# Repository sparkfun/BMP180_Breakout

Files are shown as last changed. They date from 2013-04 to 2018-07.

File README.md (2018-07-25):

**NOTE:** *This product has been retired from our catalog. If you are looking for more up-to-date info, please check out some of these resources to see how other users are still hacking and improving on this product.*
* *[SparkFun Forum](https://forum.sparkfun.com/)*
* *[Comments Here on GitHub](https://github.com/sparkfun/BMP180_Breakout_Arduino_Library/issues)*
* *[IRC Channel](https://www.sparkfun.com/news/263)*

BMP180_Breakout
===============

Breakout board and example code for the Bosch BMP180 barometric pressure sensor.

BMP180 Breakout

Product page: [www.sparkfun.com/products/11824](https://www.sparkfun.com/products/11824)

Datasheet: [github.com/sparkfun/BMP180_Breakout/blob/master/BMP180 Datasheet V2.5.pdf](https://github.com/sparkfun/BMP180_Breakout/blob/master/BMP180%20Datasheet%20V2.5.pdf?raw=true)

Github repository: [github.com/sparkfun/BMP180_Breakout](https://github.com/sparkfun/BMP180_Breakout)

Arduino library installation:
-------------------

This archive contains an Arduino library and example sketch showing how to use this sensor. The library must be installed onto your computer in order for the example code to work correctly.

If you haven't, install the free Arduino IDE (Integrated Development Environment), available at [www.arduino.cc](http://www.arduino.cc). This code was written using Arduino version 1.0.5. and updated to be used with the Arduino library manager of version 1.6.3.

To install without the manager, download the Arduino folder then use the Arduino IDE to add it.  From the IDE, go Sketch->Include Library->"Add .ZIP Library", then choose the Arduino folder that was downloaded.  The IDE will pick proper names from the library.properties file and put the libraries in your user sketch folder.

Teensy library installation:
-------------------

[A. Faruk](https://github.com/unalfaruk) was kind enough to create a version of this library for the [Teensy](https://www.pjrc.com/teensy/) microcontroller family. You can find information on installation and use of this library at: https://github.com/sparkfun/BMP180_Breakout/tree/master/Libraries/Teensy

Running the example sketch:
-------------------

<ol start=1>
<li>Connect the BMP180 breakout board to your Arduino. You can solder wires, use jumper wires and headers, etc.
<p>
"-" (GND) to GND
<br>
"+" (VDD) to 3.3V
<p>
(WARNING: do not connect "+" to 5V or the sensor will be damaged!)
<p>
You will also need to connect the I2C pins (SCL and SDA) to your Arduino.
These pins are different on different Arduino models:
<p>
<table>
<tr>
<td>Any Arduino</td>
<td>SDA&nbsp;</td>
<td>SCL</td>
</tr>
<tr>
<td>Uno, Redboard, Pro/Mini&nbsp;</td>
<td>A4</td>
<td>A5</td>
</tr>
<tr>
<td>Mega2560, Due</td>
<td>20</td>
<td>21</td>
</tr>
<tr>
<td>Leonardo, Pro/Micro</td>
<td>2</td>
<td>3</td>
</tr>
</table>
<p>
Leave the IO (VDDIO) pin unconnected. This pin is for connecting
the BMP180 to systems with lower logic levels such as 1.8V.
</li>
<li>
Connect your Arduino to your computer.
<p>
</li>
<li>
Start the Arduino IDE. Select the proper COM port and board type.
<p>
</li>
<li>
In the Arduino IDE, go to the File menu, and down to Examples/SFE_BMP180/SFE_BMP180_example. If you do not see this item, you likely did not install the library properly. See above.
<p>
</li>
<li>
Upload the sketch to your Arduino.
<p>
</li>
<li>
Open the Serial Monitor window (magnifying glass icon un upper right of IDE).
<p>
</li>
<li>
Set the Serial Monitor to 9600 baud (menu in bottom right).
<p>
</li>
</ol>
You should now be seeing pressure measurements in the Serial Monitor window. If you see errors, you may not have connected the BMP180 Breakout Board to your Arduino properly. See step 1 above.

If you have questions, don't hesistate to contact us at techsupport@sparkfun.com.

Have fun!
Your friends at SparkFun.

License Informatiom
-------------------

Software and hardware license information can be found at: https://github.com/sparkfun/BMP180_Breakout/blob/master/LICENSE.md

Authors
-------

 * Mike Grusin, SparkFun Electronics

Acknowledgements
----------------

 * The SFE_BMP180 library uses [floating-point equations](http://wmrx00.sourceforge.net/Arduino/BMP085-Calcs.pdf) for the BMP085 developed by the [Weather Station Data Logger project](http://wmrx00.sourceforge.net/).

  * Thank you to [A. Faruk](https://github.com/unalfaruk) for modifications to support the PJRC Teensy microcontroller family.

  * Thank you to [Asafe Silva](https://github.com/AsafeSilva) for providing support for alternate I2C implementations.

Changelog
---------
+ Release [V_1.1.0](https://github.com/sparkfun/BMP180_Breakout/tree/V_1.1.0)
	* Restructred for arduino IDE
	* Pulled in library

+ hardware V10 (release)

	* Minor updates
	* Library fork from SFE_BMP085

+ hardware V02 (proto)

	* Rearranged header: put VDD/GND/SDA/SCL in "standard" order
	* I2C pullups to VDDIO

+ hardware V01 (review)

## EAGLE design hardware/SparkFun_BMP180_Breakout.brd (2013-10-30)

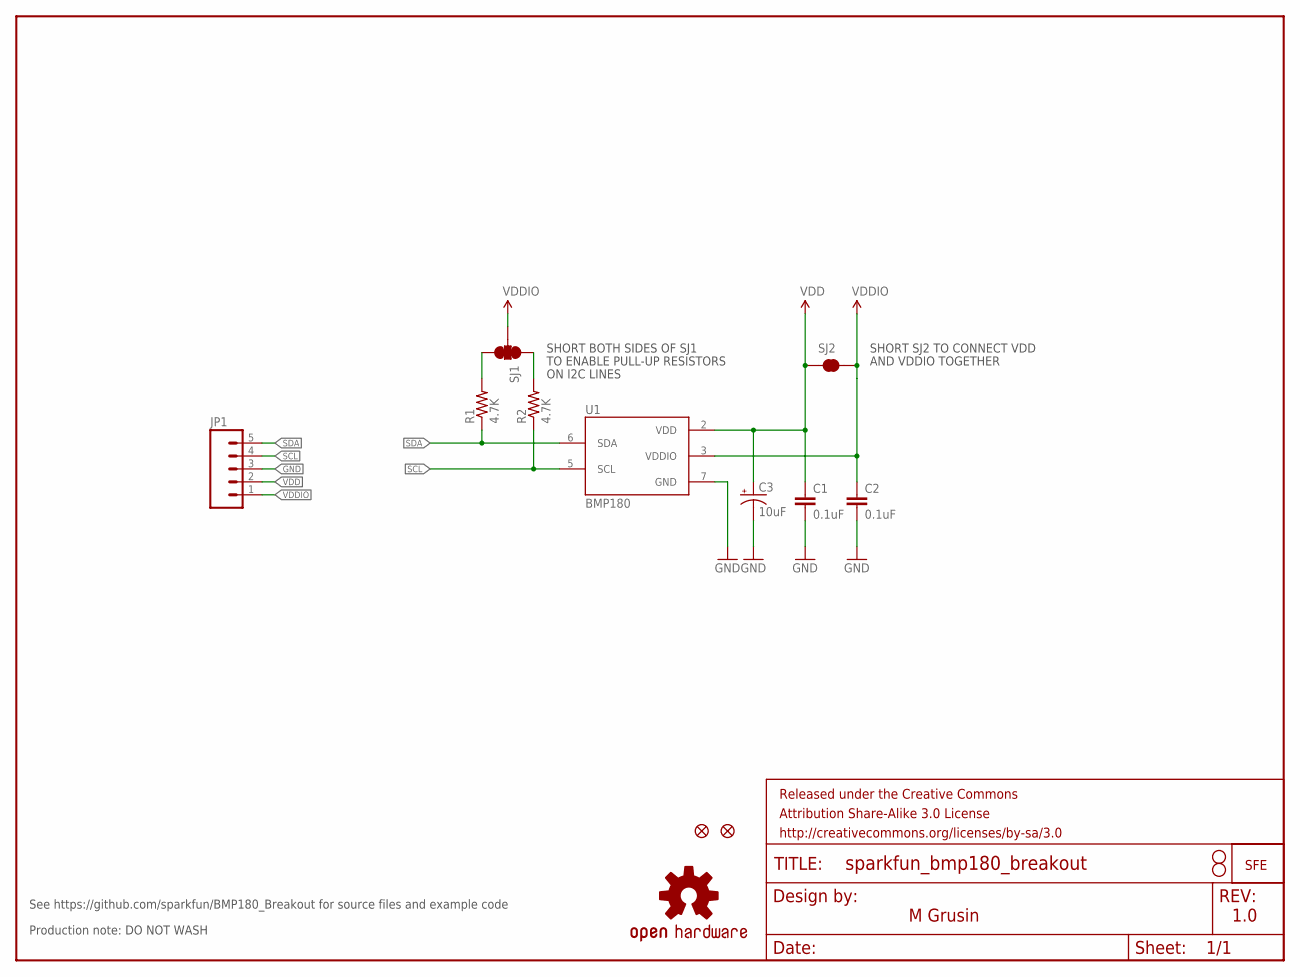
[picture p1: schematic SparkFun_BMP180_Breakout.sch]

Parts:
C1, C2: 0.1uF; 0603-CAP
C3: 10uF; EIA3216
FID1, FID2: FIDUCIALUFIDUCIAL; MICRO-FIDUCIAL
FRAME1: FRAME-LETTER; CREATIVE_COMMONS
JP1: M05_ROUNDONLY_NOSILK; 1X05_ROUNDONLY_NOSILK
LOGO1: LOGO-SFENW2; SFE-NEW-WEB
LOGO2: OSHW-LOGOS; OSHW-LOGO-S
R1, R2: 4.7K; 0603-RES
SJ1: SOLDERJUMPER_2WAYPASTE1&2&3; SJ_3_PASTE1&2&3
SJ2: SOLDERJUMPERNC; SJ_2S
STANDOFF1, STANDOFF2: STAND-OFF
U1: BMP180

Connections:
GND: C1.2, C2.2, C3.C (-), JP1.3, U1.7 (GND)
unnamed: R1.2, SJ1.3
unnamed: R2.2, SJ1.1
SCL: JP1.4, R2.1, U1.5 (SCL)
SDA: JP1.5, R1.1, U1.6 (SDA)
VDD: C1.1, C3.A (+), JP1.2, SJ2.1, U1.2 (VDD)
VDDIO: C2.1, JP1.1, SJ1.2, SJ2.2, U1.3 (VDDIO)

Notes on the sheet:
M Grusin
SHORT BOTH SIDES OF SJ1
TO ENABLE PULL-UP RESISTORS
ON I2C LINES
SHORT SJ2 TO CONNECT VDD
AND VDDIO TOGETHER
1.0
Production note: DO NOT WASH
See https://github.com/sparkfun/BMP180_Breakout for source files and example code

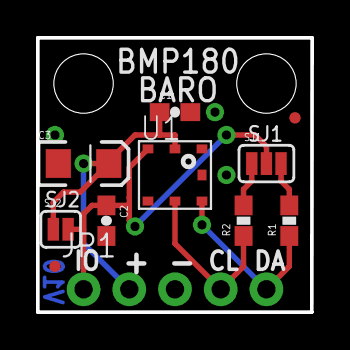
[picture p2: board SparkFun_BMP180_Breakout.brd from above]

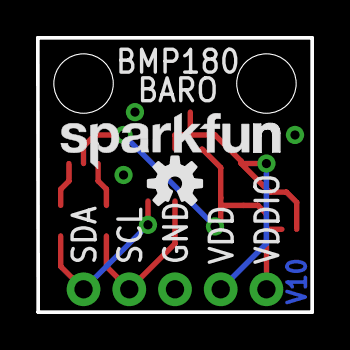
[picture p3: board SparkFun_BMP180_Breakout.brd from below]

Board: 2 copper layers, 15.2 x 15.2 mm, 16 parts (2 on the bottom side), 7 nets.

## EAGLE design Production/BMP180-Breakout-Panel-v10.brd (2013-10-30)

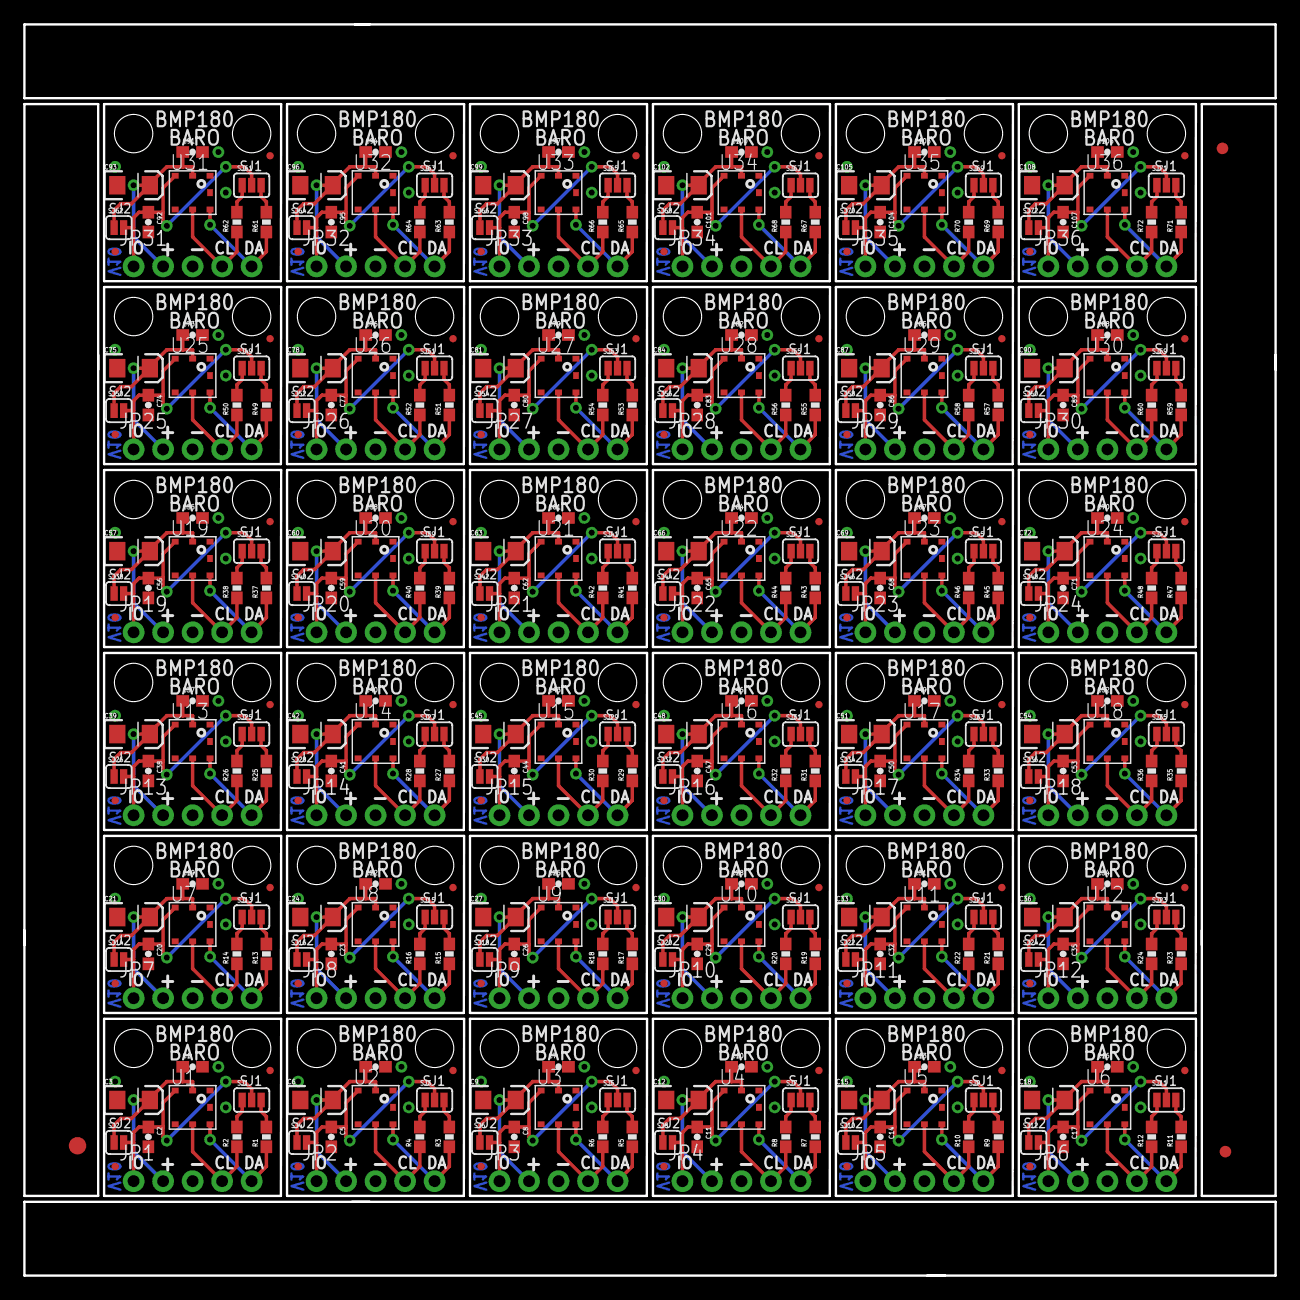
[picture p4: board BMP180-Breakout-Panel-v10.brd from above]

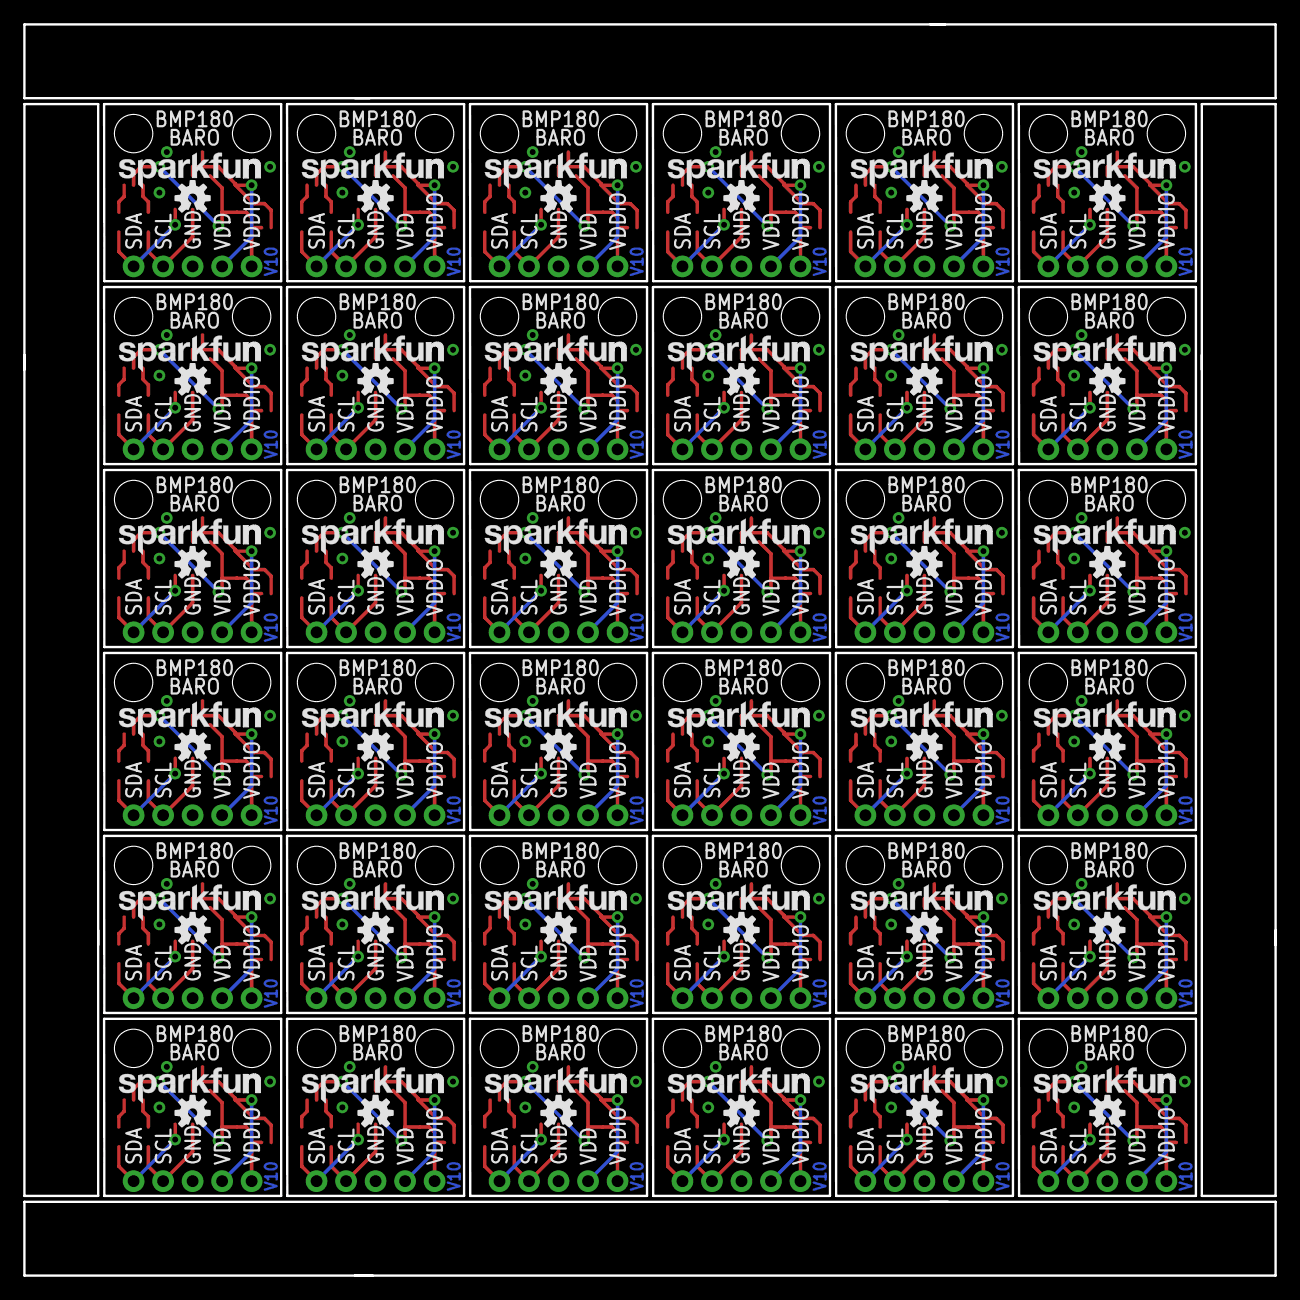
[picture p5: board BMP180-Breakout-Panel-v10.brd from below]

Board: 2 copper layers, 107.7 x 107.7 mm, 543 parts (72 on the bottom side), 252 nets.

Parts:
C1, C2, C4, C5, C7, C8, C10, C11, C13, C14, C16, C17, C19, C20, C22, C23, C25, C26, C28, C29, C31, C32, C34, C35, C37, C38, C40, C41, C43, C44, C46, C47, C49, C50, C52, C53, C55, C56, C58, C59, C61, C62, C64, C65, C67, C68, C70, C71, C73, C74, C76, C77, C79, C80, C82, C83, C85, C86, C88, C89, C91, C92, C94, C95, C97, C98, C100, C101, C103, C104, C106, C107: 0.1uF; 0603-CAP
C3, C6, C9, C12, C15, C18, C21, C24, C27, C30, C33, C36, C39, C42, C45, C48, C51, C54, C57, C60, C63, C66, C69, C72, C75, C78, C81, C84, C87, C90, C93, C96, C99, C102, C105, C108: 10uF; EIA3216
E$1: FIDUCIAL-1.5X3
E$4, E$8: FIDUCIAL-1X2
FID1, FID2, FID3, FID4, FID5, FID6, FID7, FID8, FID9, FID10, FID11, FID12, FID13, FID14, FID15, FID16, FID17, FID18, FID19, FID20, FID21, FID22, FID23, FID24, FID25, FID26, FID27, FID28, FID29, FID30, FID31, FID32, FID33, FID34, FID35, FID36, FID37, FID38, FID39, FID40, FID41, FID42, FID43, FID44, FID45, FID46, FID47, FID48, FID49, FID50, FID51, FID52, FID53, FID54, FID55, FID56, FID57, FID58, FID59, FID60, FID61, FID62, FID63, FID64, FID65, FID66, FID67, FID68, FID69, FID70, FID71, FID72: FIDUCIALUFIDUCIAL; MICRO-FIDUCIAL
JP1, JP2, JP3, JP4, JP5, JP6, JP7, JP8, JP9, JP10, JP11, JP12, JP13, JP14, JP15, JP16, JP17, JP18, JP19, JP20, JP21, JP22, JP23, JP24, JP25, JP26, JP27, JP28, JP29, JP30, JP31, JP32, JP33, JP34, JP35, JP36: 1X05_ROUNDONLY_NOSILK
LOGO1, LOGO3, LOGO5, LOGO7, LOGO9, LOGO11, LOGO13, LOGO15, LOGO17, LOGO19, LOGO21, LOGO23, LOGO25, LOGO27, LOGO29, LOGO31, LOGO33, LOGO35, LOGO37, LOGO39, LOGO41, LOGO43, LOGO45, LOGO47, LOGO49, LOGO51, LOGO53, LOGO55, LOGO57, LOGO59, LOGO61, LOGO63, LOGO65, LOGO67, LOGO69, LOGO71: LOGO-SFENW2; SFE-NEW-WEB
LOGO2, LOGO4, LOGO6, LOGO8, LOGO10, LOGO12, LOGO14, LOGO16, LOGO18, LOGO20, LOGO22, LOGO24, LOGO26, LOGO28, LOGO30, LOGO32, LOGO34, LOGO36, LOGO38, LOGO40, LOGO42, LOGO44, LOGO46, LOGO48, LOGO50, LOGO52, LOGO54, LOGO56, LOGO58, LOGO60, LOGO62, LOGO64, LOGO66, LOGO68, LOGO70, LOGO72: OSHW-LOGOS; OSHW-LOGO-S
R1, R2, R3, R4, R5, R6, R7, R8, R9, R10, R11, R12, R13, R14, R15, R16, R17, R18, R19, R20, R21, R22, R23, R24, R25, R26, R27, R28, R29, R30, R31, R32, R33, R34, R35, R36, R37, R38, R39, R40, R41, R42, R43, R44, R45, R46, R47, R48, R49, R50, R51, R52, R53, R54, R55, R56, R57, R58, R59, R60, R61, R62, R63, R64, R65, R66, R67, R68, R69, R70, R71, R72: 4.7K; 0603-RES
SJ1, SJ3, SJ5, SJ7, SJ9, SJ11, SJ13, SJ15, SJ17, SJ19, SJ21, SJ23, SJ25, SJ27, SJ29, SJ31, SJ33, SJ35, SJ37, SJ39, SJ41, SJ43, SJ45, SJ47, SJ49, SJ51, SJ53, SJ55, SJ57, SJ59, SJ61, SJ63, SJ65, SJ67, SJ69, SJ71: SJ_3_PASTE1&2&3
SJ2, SJ4, SJ6, SJ8, SJ10, SJ12, SJ14, SJ16, SJ18, SJ20, SJ22, SJ24, SJ26, SJ28, SJ30, SJ32, SJ34, SJ36, SJ38, SJ40, SJ42, SJ44, SJ46, SJ48, SJ50, SJ52, SJ54, SJ56, SJ58, SJ60, SJ62, SJ64, SJ66, SJ68, SJ70, SJ72: SJ_2S
STANDOFF1, STANDOFF2, STANDOFF3, STANDOFF4, STANDOFF5, STANDOFF6, STANDOFF7, STANDOFF8, STANDOFF9, STANDOFF10, STANDOFF11, STANDOFF12, STANDOFF13, STANDOFF14, STANDOFF15, STANDOFF16, STANDOFF17, STANDOFF18, STANDOFF19, STANDOFF20, STANDOFF21, STANDOFF22, STANDOFF23, STANDOFF24, STANDOFF25, STANDOFF26, STANDOFF27, STANDOFF28, STANDOFF29, STANDOFF30, STANDOFF31, STANDOFF32, STANDOFF33, STANDOFF34, STANDOFF35, STANDOFF36, STANDOFF37, STANDOFF38, STANDOFF39, STANDOFF40, STANDOFF41, STANDOFF42, STANDOFF43, STANDOFF44, STANDOFF45, STANDOFF46, STANDOFF47, STANDOFF48, STANDOFF49, STANDOFF50, STANDOFF51, STANDOFF52, STANDOFF53, STANDOFF54, STANDOFF55, STANDOFF56, STANDOFF57, STANDOFF58, STANDOFF59, STANDOFF60, STANDOFF61, STANDOFF62, STANDOFF63, STANDOFF64, STANDOFF65, STANDOFF66, STANDOFF67, STANDOFF68, STANDOFF69, STANDOFF70, STANDOFF71, STANDOFF72: STAND-OFF
U1, U2, U3, U4, U5, U6, U7, U8, U9, U10, U11, U12, U13, U14, U15, U16, U17, U18, U19, U20, U21, U22, U23, U24, U25, U26, U27, U28, U29, U30, U31, U32, U33, U34, U35, U36: BMP180

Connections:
GND: C1.2, C2.2, C3.C, JP1.3, U1.7
GND1: C4.2, C5.2, C6.C, JP2.3, U2.7
GND2: C7.2, C8.2, C9.C, JP3.3, U3.7
GND3: C10.2, C11.2, C12.C, JP4.3, U4.7
GND4: C13.2, C14.2, C15.C, JP5.3, U5.7
GND5: C16.2, C17.2, C18.C, JP6.3, U6.7
GND6: C19.2, C20.2, C21.C, JP7.3, U7.7
GND7: C22.2, C23.2, C24.C, JP8.3, U8.7
GND8: C25.2, C26.2, C27.C, JP9.3, U9.7
GND9: C28.2, C29.2, C30.C, JP10.3, U10.7
GND10: C31.2, C32.2, C33.C, JP11.3, U11.7
GND11: C34.2, C35.2, C36.C, JP12.3, U12.7
GND12: C37.2, C38.2, C39.C, JP13.3, U13.7
GND13: C40.2, C41.2, C42.C, JP14.3, U14.7
GND14: C43.2, C44.2, C45.C, JP15.3, U15.7
GND15: C46.2, C47.2, C48.C, JP16.3, U16.7
GND16: C49.2, C50.2, C51.C, JP17.3, U17.7
GND17: C52.2, C53.2, C54.C, JP18.3, U18.7
GND18: C55.2, C56.2, C57.C, JP19.3, U19.7
GND19: C58.2, C59.2, C60.C, JP20.3, U20.7
GND20: C61.2, C62.2, C63.C, JP21.3, U21.7
GND21: C64.2, C65.2, C66.C, JP22.3, U22.7
GND22: C67.2, C68.2, C69.C, JP23.3, U23.7
GND23: C70.2, C71.2, C72.C, JP24.3, U24.7
GND24: C73.2, C74.2, C75.C, JP25.3, U25.7
GND25: C76.2, C77.2, C78.C, JP26.3, U26.7
GND26: C79.2, C80.2, C81.C, JP27.3, U27.7
GND27: C82.2, C83.2, C84.C, JP28.3, U28.7
GND28: C85.2, C86.2, C87.C, JP29.3, U29.7
GND29: C88.2, C89.2, C90.C, JP30.3, U30.7
GND30: C91.2, C92.2, C93.C, JP31.3, U31.7
GND31: C94.2, C95.2, C96.C, JP32.3, U32.7
GND32: C97.2, C98.2, C99.C, JP33.3, U33.7
GND33: C100.2, C101.2, C102.C, JP34.3, U34.7
GND34: C103.2, C104.2, C105.C, JP35.3, U35.7
GND35: C106.2, C107.2, C108.C, JP36.3, U36.7
unnamed: R1.2, SJ1.3
unnamed: R2.2, SJ1.1
unnamed: R3.2, SJ3.3
unnamed: R4.2, SJ3.1
unnamed: R5.2, SJ5.3
unnamed: R6.2, SJ5.1
unnamed: R7.2, SJ7.3
unnamed: R8.2, SJ7.1
unnamed: R9.2, SJ9.3
unnamed: R10.2, SJ9.1
unnamed: R11.2, SJ11.3
unnamed: R12.2, SJ11.1
unnamed: R13.2, SJ13.3
unnamed: R14.2, SJ13.1
unnamed: R15.2, SJ15.3
unnamed: R16.2, SJ15.1
unnamed: R17.2, SJ17.3
unnamed: R18.2, SJ17.1
unnamed: R19.2, SJ19.3
unnamed: R20.2, SJ19.1
unnamed: R21.2, SJ21.3
unnamed: R22.2, SJ21.1
unnamed: R23.2, SJ23.3
unnamed: R24.2, SJ23.1
unnamed: R25.2, SJ25.3
unnamed: R26.2, SJ25.1
unnamed: R27.2, SJ27.3
unnamed: R28.2, SJ27.1
unnamed: R29.2, SJ29.3
unnamed: R30.2, SJ29.1
unnamed: R31.2, SJ31.3
unnamed: R32.2, SJ31.1
unnamed: R33.2, SJ33.3
unnamed: R34.2, SJ33.1
unnamed: R35.2, SJ35.3
unnamed: R36.2, SJ35.1
unnamed: R37.2, SJ37.3
unnamed: R38.2, SJ37.1
unnamed: R39.2, SJ39.3
unnamed: R40.2, SJ39.1
unnamed: R41.2, SJ41.3
unnamed: R42.2, SJ41.1
unnamed: R43.2, SJ43.3
unnamed: R44.2, SJ43.1
unnamed: R45.2, SJ45.3
unnamed: R46.2, SJ45.1
unnamed: R47.2, SJ47.3
unnamed: R48.2, SJ47.1
unnamed: R49.2, SJ49.3
unnamed: R50.2, SJ49.1
unnamed: R51.2, SJ51.3
unnamed: R52.2, SJ51.1
unnamed: R53.2, SJ53.3
unnamed: R54.2, SJ53.1
unnamed: R55.2, SJ55.3
unnamed: R56.2, SJ55.1
unnamed: R57.2, SJ57.3
unnamed: R58.2, SJ57.1
unnamed: R59.2, SJ59.3
unnamed: R60.2, SJ59.1
unnamed: R61.2, SJ61.3
unnamed: R62.2, SJ61.1
unnamed: R63.2, SJ63.3
unnamed: R64.2, SJ63.1
unnamed: R65.2, SJ65.3
unnamed: R66.2, SJ65.1
unnamed: R67.2, SJ67.3
unnamed: R68.2, SJ67.1
unnamed: R69.2, SJ69.3
unnamed: R70.2, SJ69.1
unnamed: R71.2, SJ71.3
unnamed: R72.2, SJ71.1
SCL: JP1.4, R2.1, U1.5
SCL1: JP2.4, R4.1, U2.5
SCL2: JP3.4, R6.1, U3.5
SCL3: JP4.4, R8.1, U4.5
SCL4: JP5.4, R10.1, U5.5
SCL5: JP6.4, R12.1, U6.5
SCL6: JP7.4, R14.1, U7.5
SCL7: JP8.4, R16.1, U8.5
SCL8: JP9.4, R18.1, U9.5
SCL9: JP10.4, R20.1, U10.5
SCL10: JP11.4, R22.1, U11.5
SCL11: JP12.4, R24.1, U12.5
SCL12: JP13.4, R26.1, U13.5
SCL13: JP14.4, R28.1, U14.5
SCL14: JP15.4, R30.1, U15.5
SCL15: JP16.4, R32.1, U16.5
SCL16: JP17.4, R34.1, U17.5
SCL17: JP18.4, R36.1, U18.5
SCL18: JP19.4, R38.1, U19.5
SCL19: JP20.4, R40.1, U20.5
SCL20: JP21.4, R42.1, U21.5
SCL21: JP22.4, R44.1, U22.5
SCL22: JP23.4, R46.1, U23.5
SCL23: JP24.4, R48.1, U24.5
SCL24: JP25.4, R50.1, U25.5
SCL25: JP26.4, R52.1, U26.5
SCL26: JP27.4, R54.1, U27.5
SCL27: JP28.4, R56.1, U28.5
SCL28: JP29.4, R58.1, U29.5
SCL29: JP30.4, R60.1, U30.5
SCL30: JP31.4, R62.1, U31.5
SCL31: JP32.4, R64.1, U32.5
SCL32: JP33.4, R66.1, U33.5
SCL33: JP34.4, R68.1, U34.5
SCL34: JP35.4, R70.1, U35.5
SCL35: JP36.4, R72.1, U36.5
SDA: JP1.5, R1.1, U1.6
SDA1: JP2.5, R3.1, U2.6
SDA2: JP3.5, R5.1, U3.6
SDA3: JP4.5, R7.1, U4.6
SDA4: JP5.5, R9.1, U5.6
SDA5: JP6.5, R11.1, U6.6
SDA6: JP7.5, R13.1, U7.6
SDA7: JP8.5, R15.1, U8.6
SDA8: JP9.5, R17.1, U9.6
SDA9: JP10.5, R19.1, U10.6
SDA10: JP11.5, R21.1, U11.6
SDA11: JP12.5, R23.1, U12.6
SDA12: JP13.5, R25.1, U13.6
SDA13: JP14.5, R27.1, U14.6
SDA14: JP15.5, R29.1, U15.6
SDA15: JP16.5, R31.1, U16.6
SDA16: JP17.5, R33.1, U17.6
SDA17: JP18.5, R35.1, U18.6
SDA18: JP19.5, R37.1, U19.6
SDA19: JP20.5, R39.1, U20.6
SDA20: JP21.5, R41.1, U21.6
SDA21: JP22.5, R43.1, U22.6
SDA22: JP23.5, R45.1, U23.6
SDA23: JP24.5, R47.1, U24.6
SDA24: JP25.5, R49.1, U25.6
SDA25: JP26.5, R51.1, U26.6
SDA26: JP27.5, R53.1, U27.6
SDA27: JP28.5, R55.1, U28.6
SDA28: JP29.5, R57.1, U29.6
SDA29: JP30.5, R59.1, U30.6
SDA30: JP31.5, R61.1, U31.6
SDA31: JP32.5, R63.1, U32.6
SDA32: JP33.5, R65.1, U33.6
SDA33: JP34.5, R67.1, U34.6
SDA34: JP35.5, R69.1, U35.6
SDA35: JP36.5, R71.1, U36.6
VDD: C1.1, C3.A, JP1.2, SJ2.1, U1.2
VDD1: C4.1, C6.A, JP2.2, SJ4.1, U2.2
VDD2: C7.1, C9.A, JP3.2, SJ6.1, U3.2
VDD3: C10.1, C12.A, JP4.2, SJ8.1, U4.2
VDD4: C13.1, C15.A, JP5.2, SJ10.1, U5.2
VDD5: C16.1, C18.A, JP6.2, SJ12.1, U6.2
VDD6: C19.1, C21.A, JP7.2, SJ14.1, U7.2
VDD7: C22.1, C24.A, JP8.2, SJ16.1, U8.2
VDD8: C25.1, C27.A, JP9.2, SJ18.1, U9.2
VDD9: C28.1, C30.A, JP10.2, SJ20.1, U10.2
VDD10: C31.1, C33.A, JP11.2, SJ22.1, U11.2
VDD11: C34.1, C36.A, JP12.2, SJ24.1, U12.2
VDD12: C37.1, C39.A, JP13.2, SJ26.1, U13.2
VDD13: C40.1, C42.A, JP14.2, SJ28.1, U14.2
VDD14: C43.1, C45.A, JP15.2, SJ30.1, U15.2
VDD15: C46.1, C48.A, JP16.2, SJ32.1, U16.2
VDD16: C49.1, C51.A, JP17.2, SJ34.1, U17.2
VDD17: C52.1, C54.A, JP18.2, SJ36.1, U18.2
VDD18: C55.1, C57.A, JP19.2, SJ38.1, U19.2
VDD19: C58.1, C60.A, JP20.2, SJ40.1, U20.2
VDD20: C61.1, C63.A, JP21.2, SJ42.1, U21.2
VDD21: C64.1, C66.A, JP22.2, SJ44.1, U22.2
VDD22: C67.1, C69.A, JP23.2, SJ46.1, U23.2
VDD23: C70.1, C72.A, JP24.2, SJ48.1, U24.2
VDD24: C73.1, C75.A, JP25.2, SJ50.1, U25.2
VDD25: C76.1, C78.A, JP26.2, SJ52.1, U26.2
VDD26: C79.1, C81.A, JP27.2, SJ54.1, U27.2
VDD27: C82.1, C84.A, JP28.2, SJ56.1, U28.2
VDD28: C85.1, C87.A, JP29.2, SJ58.1, U29.2
VDD29: C88.1, C90.A, JP30.2, SJ60.1, U30.2
VDD30: C91.1, C93.A, JP31.2, SJ62.1, U31.2
VDD31: C94.1, C96.A, JP32.2, SJ64.1, U32.2
VDD32: C97.1, C99.A, JP33.2, SJ66.1, U33.2
VDD33: C100.1, C102.A, JP34.2, SJ68.1, U34.2
VDD34: C103.1, C105.A, JP35.2, SJ70.1, U35.2
VDD35: C106.1, C108.A, JP36.2, SJ72.1, U36.2
VDDIO: C2.1, JP1.1, SJ1.2, SJ2.2, U1.3
VDDIO1: C5.1, JP2.1, SJ3.2, SJ4.2, U2.3
VDDIO2: C8.1, JP3.1, SJ5.2, SJ6.2, U3.3
VDDIO3: C11.1, JP4.1, SJ7.2, SJ8.2, U4.3
VDDIO4: C14.1, JP5.1, SJ9.2, SJ10.2, U5.3
VDDIO5: C17.1, JP6.1, SJ11.2, SJ12.2, U6.3
VDDIO6: C20.1, JP7.1, SJ13.2, SJ14.2, U7.3
VDDIO7: C23.1, JP8.1, SJ15.2, SJ16.2, U8.3
VDDIO8: C26.1, JP9.1, SJ17.2, SJ18.2, U9.3
VDDIO9: C29.1, JP10.1, SJ19.2, SJ20.2, U10.3
VDDIO10: C32.1, JP11.1, SJ21.2, SJ22.2, U11.3
VDDIO11: C35.1, JP12.1, SJ23.2, SJ24.2, U12.3
VDDIO12: C38.1, JP13.1, SJ25.2, SJ26.2, U13.3
VDDIO13: C41.1, JP14.1, SJ27.2, SJ28.2, U14.3
VDDIO14: C44.1, JP15.1, SJ29.2, SJ30.2, U15.3
VDDIO15: C47.1, JP16.1, SJ31.2, SJ32.2, U16.3
VDDIO16: C50.1, JP17.1, SJ33.2, SJ34.2, U17.3
VDDIO17: C53.1, JP18.1, SJ35.2, SJ36.2, U18.3
VDDIO18: C56.1, JP19.1, SJ37.2, SJ38.2, U19.3
VDDIO19: C59.1, JP20.1, SJ39.2, SJ40.2, U20.3
VDDIO20: C62.1, JP21.1, SJ41.2, SJ42.2, U21.3
VDDIO21: C65.1, JP22.1, SJ43.2, SJ44.2, U22.3
VDDIO22: C68.1, JP23.1, SJ45.2, SJ46.2, U23.3
VDDIO23: C71.1, JP24.1, SJ47.2, SJ48.2, U24.3
VDDIO24: C74.1, JP25.1, SJ49.2, SJ50.2, U25.3
VDDIO25: C77.1, JP26.1, SJ51.2, SJ52.2, U26.3
VDDIO26: C80.1, JP27.1, SJ53.2, SJ54.2, U27.3
VDDIO27: C83.1, JP28.1, SJ55.2, SJ56.2, U28.3
VDDIO28: C86.1, JP29.1, SJ57.2, SJ58.2, U29.3
VDDIO29: C89.1, JP30.1, SJ59.2, SJ60.2, U30.3
VDDIO30: C92.1, JP31.1, SJ61.2, SJ62.2, U31.3
VDDIO31: C95.1, JP32.1, SJ63.2, SJ64.2, U32.3
VDDIO32: C98.1, JP33.1, SJ65.2, SJ66.2, U33.3
VDDIO33: C101.1, JP34.1, SJ67.2, SJ68.2, U34.3
VDDIO34: C104.1, JP35.1, SJ69.2, SJ70.2, U35.3
VDDIO35: C107.1, JP36.1, SJ71.2, SJ72.2, U36.3

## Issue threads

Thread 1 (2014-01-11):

Possible error in ReadInt

geoffreymbrown, 2014-01-11:
The code is:

char SFE_BMP180::readInt(char address, int &value)
// Read a signed integer (two bytes) from device
// address: register to start reading (plus subsequent register)
// value: external variable to store data (function modifies value)
{
        unsigned char data[2];

        data[0] = address;
        if (readBytes(data,2))
        {
                value = (((int)data[0]<<8)|(int)data[1]);
                //if (*value & 0x8000) *value |= 0xFFFF0000; // sign extend if negative
                return(1);
        }
        value = 0;
        return(0);
}

I believe the line writing value should be

value = (int) ((data[0] << 8) | (data[1]));

Certainly the cast  ((int) data[1]) is wrong -- if the msb of data[1] is 1, then this cast will sign extend which you don't want.

tytower, 2015-05-29:
Nobody is employed to correct these I guess . Jan 2014? So is the above correct or what?

tytower, 2015-05-30:
I made the change and my BMP180 being read by an 80 Mhz ESP8622 started to read properly again. It was reading 100 degrees c instead of 20 and minus thousands for pressure instead of 30 hg. It read fine on the 18Mhz ATmega328p as it was
Thanks for the find!

tytower, 2015-05-30:
I also see an identical line in char SFE_BMP180::readUInt(char address, uint16_t &value)
Should that be changed also?

ToniCorinne, 2015-06-02:
The issue has been fixed. Please keep in mind that we have a large number of repos and a small number of people looking at them at any given time. In the future, if you find a bug you'd like us to address, please consider using the pull request system used in git/GitHub. It makes us easier to debug possible problems, and allows you to get credit for the patch. It also speeds up the process of us checking suggested fixes.

tytower, 2015-06-02:
So  geoffreymbrown I guess this means Thank You very much but Sparkfun are not of a pursuasion or upbringing to say so directly but I do Thanks

mgrusin, 2015-06-02:
Toni, did you happen to test the requested fix on a BMP180 connected to a standard Arduino? I am worried that this "fix" may have broken it.

tytower, just so you know, the existing code works(ed) correctly on the Arduino because it was coded to the datatype widths present on that platform. The reason it broke on your system is because your system uses different datatype widths. A better fix to this problem is to specify overt widths for all library variables (d_typeXX) to support other architectures, which is something that wasn't an issue when the library was written. I also believe the suggested fix is incorrect, but I'm glad it works for you. If you eventually run into weird values on your system, you'll know where they came from.

ToniCorinne, 2015-06-02:
@mgrusin I have it up and running in my office if you'd like to come check it out.

mgrusin, 2015-06-02:
Thanks Toni.

tytower, 2015-06-04:
Appreciate the reply thanks Mike
----------------------------------------------------------------------On Tue, 02 Jun 2015 15:11:55 -0700
Mike Grusin <notifications@github.com> wrote:

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

--
Yahoo <tytower@yahoo.com>

tytower, 2015-06-04:
Sparkfun's librarys in the new Arduino IDE

Your Sensor library MPL3115A2  contains an invalid character in the name and this causes 15 error windows every time Arduino is started .

It has to be fixed on your end as it is coming up with that name in the boards manager and can't be changed by me

--
Yahoo <tytower@yahoo.com>

tytower, 2015-06-04:
NOT HAPPY SPARKFUN!

Sparkfun's librarys in the new Arduino IDE

Your Sensor library MPL3115A2  contains an invalid character in the name and this causes 15 error windows every time Arduino is started .

It has to be fixed on your end as it is coming up with that name in the boards manager and can't be changed by me

--
Yahoo <tytower@yahoo.com>

mgrusin, 2015-06-05:
Thank you for the report, we will look into it.

In the meantime, you should be able to download and install the library manually.

tytower, 2015-06-05:
I have had to re download  the IDE complete and start again with libraries but I have still not found how to stop these windows 16 at a time and they started after I followed your instructions for adding a zip file?
See the attaches screen shot 16 times every time i start the ide and a couple each time I restart the Serial terminal --Crazy

On Thu, 04 Jun 2015 18:22:57 -0700
Mike Grusin <notifications@github.com> wrote:

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

--
Yahoo <tytower@yahoo.com>

Closed 2015-06-02.

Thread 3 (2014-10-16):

Minimal change in pressure & no change in altitude

gioalex, 2014-10-16:
I've tried this drive but I get some problem with calculated value as described in the object.
I'm trying to understand if there are some casting problem.

Best regards
Alessandro

ToniCorinne, 2015-06-02:
Sorry for the delayed response @gioalex . If you are still having problems, please try updating to the most recent version of the library. If that does not fix the issue, please provide more information regarding what code you are using, what results you are getting, and what your circuit looks like. Thanks!

Closed 2015-06-02.

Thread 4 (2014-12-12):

Can you send the data from 1 BMP180 sensor to 2 different Arduino Unos?

pradk1, 2014-12-12:
Can you send the data from 1 BMP180 sensor to 2 different Arduino Unos? This is so I can simulate the data in 2 different ways using 2 different serial ports. There would only by 1 3.3V power supply and the grounds would all be connected together properly, but the SDA and SCL pins would be connected to both Arduino Unos on the same pins (A4 & A5). I'm not sure if it's possible, but I thought I would ask. Thank you!

arashmarzi, 2015-05-26:
What if the scenario is that you have a Raspberry Pi that is the master, an Arduino Micro is a slave to the Pi, and the BMP180 that is a slave to the Micro, so something like this:
Pi (gets data from) <-- Arduino (gets data from) <-- BMP180 (collects data)

would this be possible?

mgrusin, 2015-05-26:
You may be overcomplicating things. The data you get from the BMP180 is what it is, and would be the same for both Arduinos. How about having one Arduino retrieve the raw data, process the data both ways, and send one result to the hardware serial port, and the other result to a software serial port?

ToniCorinne, 2015-06-02:
Closing this issue out as two possible fixes have been addressed. Please reopen if you have additional questions.

Closed 2015-06-02.

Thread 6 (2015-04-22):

Having both .startTemperature and .startPressure open at the same time

Avraamu, 2015-04-22:
Hi,
I found a little annoyance in this library, when you have both startTemperature and startPressure active,  the getTemperature and the get getPressure method output weird values.
Maybe usefull to not in the documentation that this isn't possible.
Regards

ToniCorinne, 2015-06-02:
Can you give us some more information about the issue you're finding? Are you using the default sketches or have you modified them somehow?

mgrusin, 2015-06-02:
It makes sense that you'd get weird values; the part only supports reading the pressure or temperature at any given time. I think this is clear in the example code, but I'll look again and see if there's a place to specifically warn against this. Thanks for the report!

arosjoa, 2015-08-02:
You need to start a reading, use delay (status), then again get the reading with the delay (status) condition. That way it will get the right reading. I learned that the hard way.

Closed 2015-06-02.

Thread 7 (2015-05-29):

Not loading library

tytower, 2015-05-29:
I think you should include a note for anyone downloading the zip file that  you must go to the Library/Arduino directory and only copy the 6 files there (examples etc )to leave under SFE_BMP180 otherwise its a ballsup with all the other stuff you have in there!

mgrusin, 2015-06-01:
Sorry for the confusion. We've tried to make this clear in our step-by-step tutorials, but because of the way Github works you can only download everything at once. To solve this we are currently splitting all of our product repositories into separate hardware and Arduino libraries, so this should be easier in the future. (In fact, you should soon be able to add libraries from within the Arduino IDE!) Thanks for the feedback!

tytower, 2015-06-01:
Thanks Mike . Thats a good system it seems especially as it updates each time you open the IDE

While I have you there...There is an issue with the BMP180 library that needs repairing . I sent you another email to technical but have had no response here is the link
https://github.com/sparkfun/BMP180_Breakout/issues/1#issuecomment-106976786

I repaired my library and it definately seems to have fixed my issue .
Cheers from the Great Barrier Reef
--------------------------------------------------------------------------On Mon, 01 Jun 2015 10:22:03 -0700
Mike Grusin <notifications@github.com> wrote:

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

--
Yahoo <tytower@yahoo.com>

ToniCorinne, 2015-06-02:
Because of the new Arduino IDE requirements, we've also split all of our libraries into their own repositories, which negates the .zip issue.  You can find the library [here](https://github.com/sparkfun/BMP180_Breakout_Arduino_Library). The libraries are synced with the product repos using git subtree commands.

Closed 2015-06-02.

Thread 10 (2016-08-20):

No need to wait for data after Wire.requestFrom()

Koepel, 2016-08-20:
See : https://github.com/sparkfun/BMP180_Breakout_Arduino_Library/issues/3

Grahldg, 2018-07-25:
Thank you for bringing this to our attention.  Unfortunately this product is retired.  The repository will remain available as an archive for reference, but will no longer be maintained.  If you have further questions about this product please refer to our [forum](https://forum.sparkfun.com).

Closed 2018-07-25.

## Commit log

2013-04-16 minor changes to eagle files re. group review
    [BMP180 breakout v02.brd, BMP180 breakout v02.sch]
2013-04-16 final proto hardware, initial library
    Library copied and renamed from BMP085 floating-point library (see USB
    Weather Board)
    [BMP180 breakout v02.brd, BMP180 breakout v02.sch]
2013-10-25 Review for reds
    Minor updates to PCB, updated library and example code, added datasheet
    and readme
    [BMP180 breakout.brd, BMP180 breakout.sch]
2013-10-28 Minor changes for reds (V10)
    Added silk to solder jumpers
    Added BMP180 part to SparkFun Eagle Libraries
    [BMP180 breakout.brd, BMP180 breakout.sch]
2013-10-30 Added microfiducials
    [BMP180 breakout.brd, BMP180 breakout.sch]
2013-10-30 Created Panel
    [BMP180-Breakout-Panel-v10.brd]
2015-03-04 Changing 16 bit Arduino integers to uint16_t to make it compatible with 32b Teensy integers (and possibly Arduino Due's)
2015-04-26 Squashed 'Libraries/Arduino/' content from commit ee6ef49
    git-subtree-dir: Libraries/Arduino
    git-subtree-split: ee6ef491cf48a35091de4cd5d86c529a7980a9df
2015-04-26 Updating to new library structure
    [BMP180-Breakout-Panel-v10.brd]
2015-04-29 Squashed 'Libraries/Arduino/' content from commit 2ba6578
    git-subtree-split: 2ba6578635be3bbba9798e9826d1f68f2fc34cd3
    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
2015-06-02 Updating repo files, moving datasheet to documentation directory
    [SparkFun_BMP180_Breakout.brd, SparkFun_BMP180_Breakout.sch]
2017-11-22 Update SFE_BMP180.h
    Update to use other instances of the 'Wire.h' Library
2017-11-22 Update SFE_BMP180.cpp
    Update to use other instances of the Wire Library
2018-02-25 BMP180 Library for Teensy. v1
2018-02-25 Update README.md
    Info Teensyduino
2018-04-14 Multiple interface feature is added. This library can be used with Teensy/Arduino devices that has multiple i2c interfaces.
2018-04-14 This source cod for users who want to work with i2c_t3 library.

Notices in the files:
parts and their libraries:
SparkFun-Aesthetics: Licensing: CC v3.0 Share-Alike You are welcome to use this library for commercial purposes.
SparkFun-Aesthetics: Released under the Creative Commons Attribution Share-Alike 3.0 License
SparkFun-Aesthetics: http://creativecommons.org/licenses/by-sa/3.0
